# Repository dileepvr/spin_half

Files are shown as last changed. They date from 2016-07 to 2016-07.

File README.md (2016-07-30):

This board design, as well as course teaching materials and avr-gcc
code are being released under the GPL_v3 license. All future versions
of GPL automatically apply.

Written by Dileep V. Reddy on March 6th, 2014.

This simple board is meant to aid in teaching Quantum Key Distribution
via polarized photons (BB84 protocol) using an interactive in-class
activity. This was first designed for and deployed at a pilot course
titled "Quantum Mechanics for Everyone" under the aegis of the Science
Literacy Program (SPL) at the University of Oregon.

The board PCB layout files are zipped in the gerber folder, and may be
uploaded to any online PCB printing service (such as OSHPark).  The
code meant to run on the attiny2313 microcontroller is presend inside
the avr_code folder, along with a Makefile. Use avr-gcc and avrdude to
compile and upload to the board.

Refer to files "spin_half_doc.pdf" and "qkd_handout.pdf" for more
information.

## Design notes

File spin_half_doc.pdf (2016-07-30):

# Spin-half board documentation v1.0a

- Dileep V. Reddy, Last Modified March 6, 2014

The SLP Spin-half board was designed to be used as a teaching aid in the course CHC 441: Quantum Mechanics for Everyone, which was offered at the University of Oregon during the Spring term of 2014. It is meant to simulate a measurement on a spin-half particle in activities aimed at teaching students about Hilbert-spaces and the Born rule. Figure 1 shows the top view of the board, which is 1.5

00 × 1.5

00 in area.

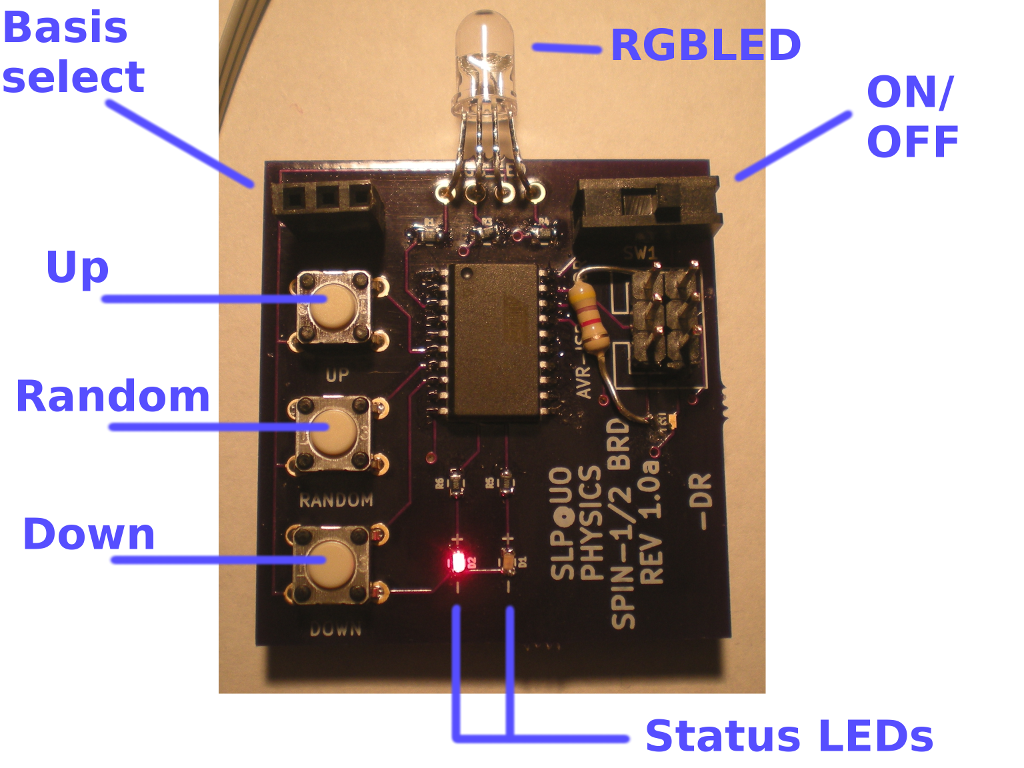
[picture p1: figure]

Figure 1: Top view of the spin-half board with essential labels.

As shown in Fig. 1, for inputs the board consists of a power (on/off) switch, a “basis-control” switch, and three tactile push-buttons labeled ‘Up’, ‘Random,’ and ‘Down’. In some versions the basis-control switch is replaced by a 3-pin female header, which allows for a wired-extension for the switch (See Fig. 2). For outputs, the board has an RGB LED mounted in front, and two status LEDs (one red and one green). The board also consists of an atmel ATTINY2313 microcontroller chip, six programming headers, assorted surface-mounted resistors, and a socket for a 3V 2032 button-cell for power on the bottom-side.

When the board is powered on, if properly pre-programmed, one of the two status LEDs should be lit up. This indicates the ‘mode’ the board is currently operating in. If the red status LED is lit, then the board is said to be in the red/blue mode. In this mode, pushing the ‘Up’(‘Down’) button will cause the RGB LED to glow red(blue). Pushing the ‘Random’ button will pick one of the two colors at random.

1

Otherwise, if the green status LED is lit, then the board is in the green/white mode. In this mode, pushing the ‘Up’(‘Down’) button will cause the RGB LED to glow green(white). Pushing the ‘Random’ button will pick one of the two colors at random. The mode can be toggled via the basis-control switch.

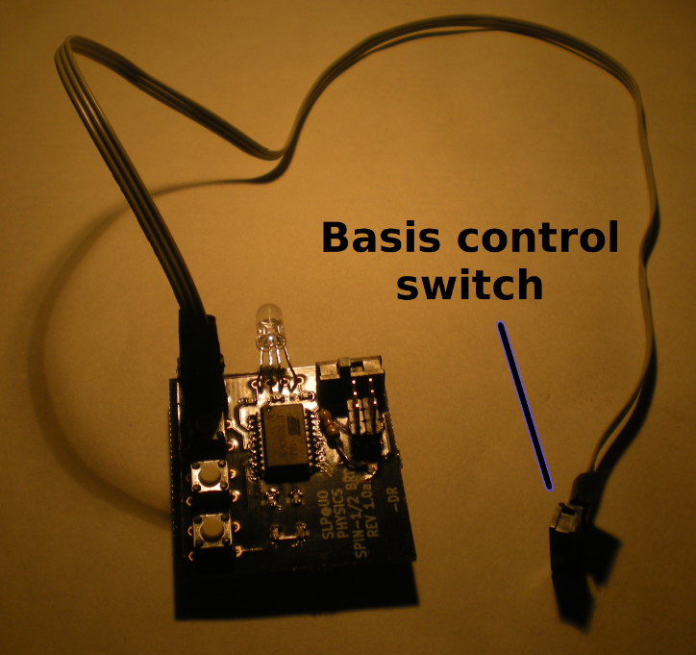
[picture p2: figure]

Figure 2: The basis-control switch may be connected with a wired-extension.

In activities, the student holding the board plays the role of the spin-half particle, while the student with the basis-control switch plays the role of the experimenter. The two modes are noncommuting basis choices. The spin-half student must first be aware of his/her state. Then the experimenter picks a basis(mode) for measurement. The spin-half particle then consults Table 1 and yields a response accordingly. After the “measurement” the spin-half particle updates his/her state to match the experimental outcome, thereby obeying the Born rule.

Table 1: Spin-half State-response look-up.

State | R/B-mode response | G/W-mode response
R B G W | R B RANDOM RANDOM | RANDOM RANDOM G W

2

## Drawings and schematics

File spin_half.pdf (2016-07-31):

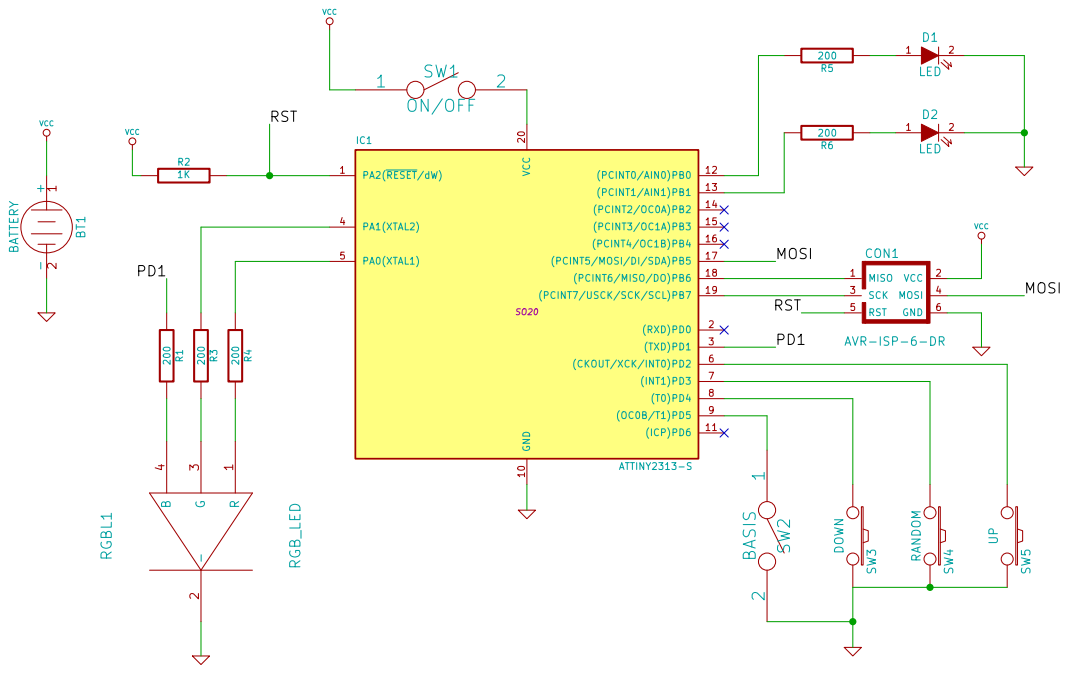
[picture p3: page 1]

Id: 1/1 Title: File: spin_half.sch
Sheet: /

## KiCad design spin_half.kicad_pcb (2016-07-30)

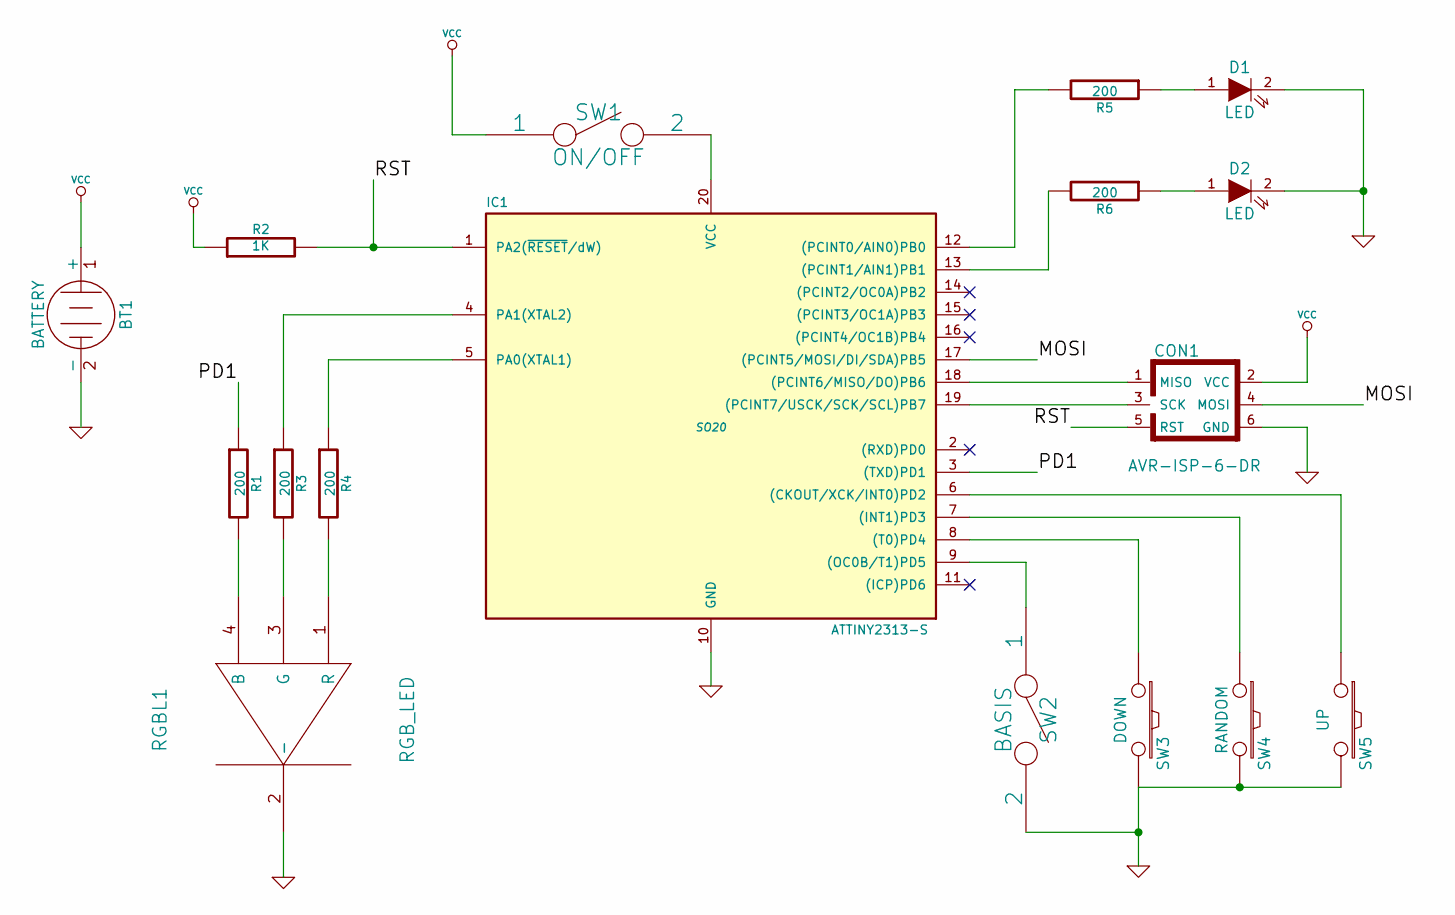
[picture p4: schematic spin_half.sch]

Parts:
BT1: BATTERY
CON1: AVR-ISP-6-DR; AVR-ISP-6
D1, D2: LED
IC1: ATTINY2313-S; SO20
R1, R3, R4, R5, R6: 200
R2: 1K
RGBL1: RGB_LED
SW1: ON/OFF
SW2: BASIS
SW3: DOWN
SW4: RANDOM
SW5: UP

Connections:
/MOSI: CON1.4 (MOSI), IC1.17 ((PCINT5/MOSI/DI/SDA)PB5)
/PD1: IC1.3 ((TXD)PD1), R1.1
/RST: CON1.5 (RST), IC1.1 (PA2(~RESET~/dW)), R2.2
GND: BT1.2 (-), CON1.6 (GND), D1.2 (K), D2.2 (K), IC1.10 (GND), RGBL1.2 (-), SW2.2, SW3.2, SW4.2, SW5.2
unnamed: IC1.9 ((OC0B/T1)PD5), SW2.1
unnamed: IC1.8 ((T0)PD4), SW3.1
unnamed: IC1.7 ((INT1)PD3), SW4.1
unnamed: IC1.5 (PA0(XTAL1)), R4.1
unnamed: CON1.1 (MISO), IC1.18 ((PCINT6/MISO/DO)PB6)
unnamed: CON1.3 (SCK), IC1.19 ((PCINT7/USCK/SCK/SCL)PB7)
unnamed: R4.2, RGBL1.1 (R)
unnamed: IC1.4 (PA1(XTAL2)), R3.1
unnamed: R3.2, RGBL1.3 (G)
unnamed: R1.2, RGBL1.4 (B)
unnamed: IC1.12 ((PCINT0/AIN0)PB0), R5.2
unnamed: D2.1 (A), R6.1
unnamed: D1.1 (A), R5.1
unnamed: IC1.13 ((PCINT1/AIN1)PB1), R6.2
unnamed: IC1.6 ((CKOUT/XCK/INT0)PD2), SW5.1
unnamed: IC1.20 (VCC), SW1.2
VCC: BT1.1 (+), CON1.2 (VCC), R2.1, SW1.1

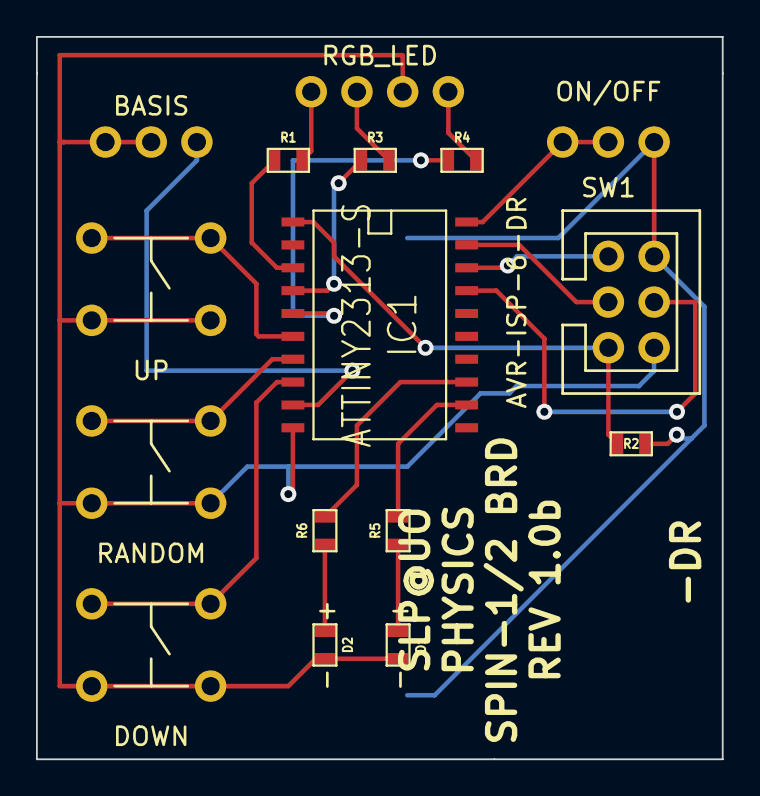
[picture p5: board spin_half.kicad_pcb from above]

Board: 2 copper layers, 38.1 x 40.1 mm, 17 parts (1 on the bottom side), 21 nets.

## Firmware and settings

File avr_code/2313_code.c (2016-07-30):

/*
This board design, as well as course teaching materials and avr-gcc
code are being released under the GPL_v3 license. All future versions
of GPL automatically apply.

Written by Dileep V. Reddy on March 6th, 2014.

*/
#include<avr/io.h>
#include<util/delay.h>
#include<avr/sfr_defs.h>

unsigned long ontime = (F_CPU/2);
unsigned long cooldown = (F_CPU/5);

unsigned long curtime, lastswitchon, lastalloff;

long int randnum;
long int maxnum;

// boolarray = {switchstate, basis}
char boolarray;

#define M 0x7FFFFFFF  // 2^31-1, the modulus used by the psuedo-random

long int prng(long int x) {  //random number generator; call with 1 <= x <=M-1
 x = (x >> 16) + ((x << 15) & M)  - (x >> 21) - ((x << 10) & M);
 if (x < 0) x += M;
 return x;
}

void statredon()
{
  PORTB |=1<<PB0;
  PORTB &= ~(1<<PB1);
}

void statgreenon()
{
  PORTB |=1<<PB1;
  PORTB &= ~(1<<PB0);
}

void blueon()
{
  PORTD |=1<<PD1;
}

void greenon()
{
  PORTA |=1<<PA1;
}

void redon()
{
  PORTA |=1<<PA0;
}

void whiteon()
{
  redon(); greenon(); blueon();
}

void alloff()
{
  PORTD &= ~(1<<PD1); PORTA &= ~(1<<PA1); PORTA &= ~(1<<PA0);
}

int main()
{
  
  // RGB LED outputs
  DDRD |=1<<PD1; DDRA |=1<<PA0; DDRA |= 1<<PA1;
  // BASIS LED outputs
  DDRB |=1<<PB0; DDRB |=1<<PB1;
  // Basis change switch
  DDRD |=0<<PD5;
  // Up, Random and Down switch
  DDRD |=0<<PD2; DDRD |=0<<PD3; DDRD |=0<<PD4;

  // Pull up input switches, turn off LEDs
  PORTD = 0b00111100;
  PORTA = 0x00;
  PORTB = 0x00;

  boolarray = 0x00;
  curtime = 0; lastswitchon = 0; lastalloff = 0;
  TCCR1B |= 1<<CS10;    // Start timer

  maxnum = 0x3FFFFFFF;
  randnum = prng(curtime);

  while(1)
    {
      curtime += TCNT1; TCNT1 = 0;
      
      // Check basis switch
      if (bit_is_set(PIND,5))
	{
	  boolarray |= 0x01;  // basis is 1
	  statredon();
	}
      else
	{
	  boolarray &= 0xFE;  // basis is 0
	  statgreenon();
	}

      if((bit_is_clear(boolarray,1))&&((curtime-lastalloff)>cooldown))
	// switchstate == FALSE && LEDs have cooled down
	{
	  // check Up switch
	  if (bit_is_clear(PIND,2))
	    {
	      lastswitchon = curtime;
	      boolarray |= 0x02;      // switchstate = TRUE
	      if (boolarray & 0x01)
		redon();
	      else
		greenon(); 
	    }
	  // check Random switch
	  else if (bit_is_clear(PIND,3)) 
	    {
	      lastswitchon = curtime;
	      boolarray |= 0x02;      // switchstate = TRUE
	      randnum = prng(curtime);
	      if (boolarray & 0x01)
		{
		  if (randnum > maxnum)
		    blueon();
		  else
		    redon();
		}
	      else
		{
		  if (randnum > maxnum)
		    whiteon();
		  else
		    greenon();
		}
	    }
	  // check Down switch
	  else if (bit_is_clear(PIND,4))
	    {
	      lastswitchon = curtime;
	      boolarray |= 0x02;      // switchstate = TRUE
	      if (boolarray & 0x01)
		blueon();
	      else
		whiteon(); 
	    }
	}
      if ((boolarray & 0x02)&&((curtime - lastswitchon) > ontime))
	// switchstate == TRUE && LEDs have been on long enough
	{
	  lastalloff = curtime;
	  boolarray &= 0b11111101;   // switch = FALSE
	  alloff();
	}
    }
  
}

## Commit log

2016-07-30 kicad and avr code in.
    [spin_half-B_Cu.gbl, spin_half-B_Mask.gbs, spin_half-B_SilkS.gbo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]
2016-07-31 Added schematic pdf.
